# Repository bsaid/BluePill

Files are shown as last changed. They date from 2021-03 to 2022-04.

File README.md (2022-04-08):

# BluePill

This project is a mess and it has never been tested.

The goal is to make STM32F103C BluePill compatible PCB with safety resistors, robust power supply with protections and SD card addon using a stacked PCB. The project is designed in [KiCad](https://www.kicad.org/) with design rules for [JLCPCB](https://jlcpcb.com/) including SMT assembly with their LCSC parts library.

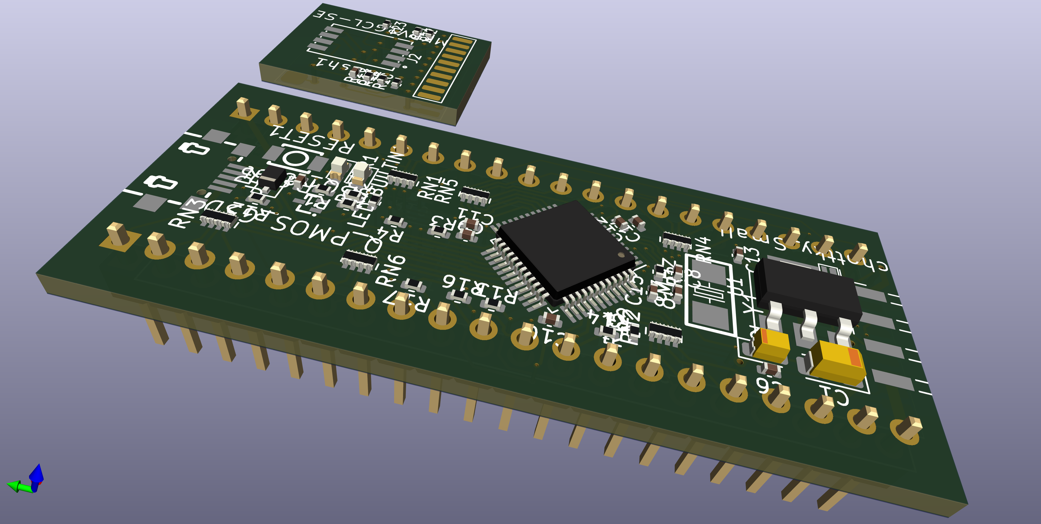
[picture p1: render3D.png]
Render


This PCB was never tested or manufactured because the STM32 microcontrollers are out of stock globally.

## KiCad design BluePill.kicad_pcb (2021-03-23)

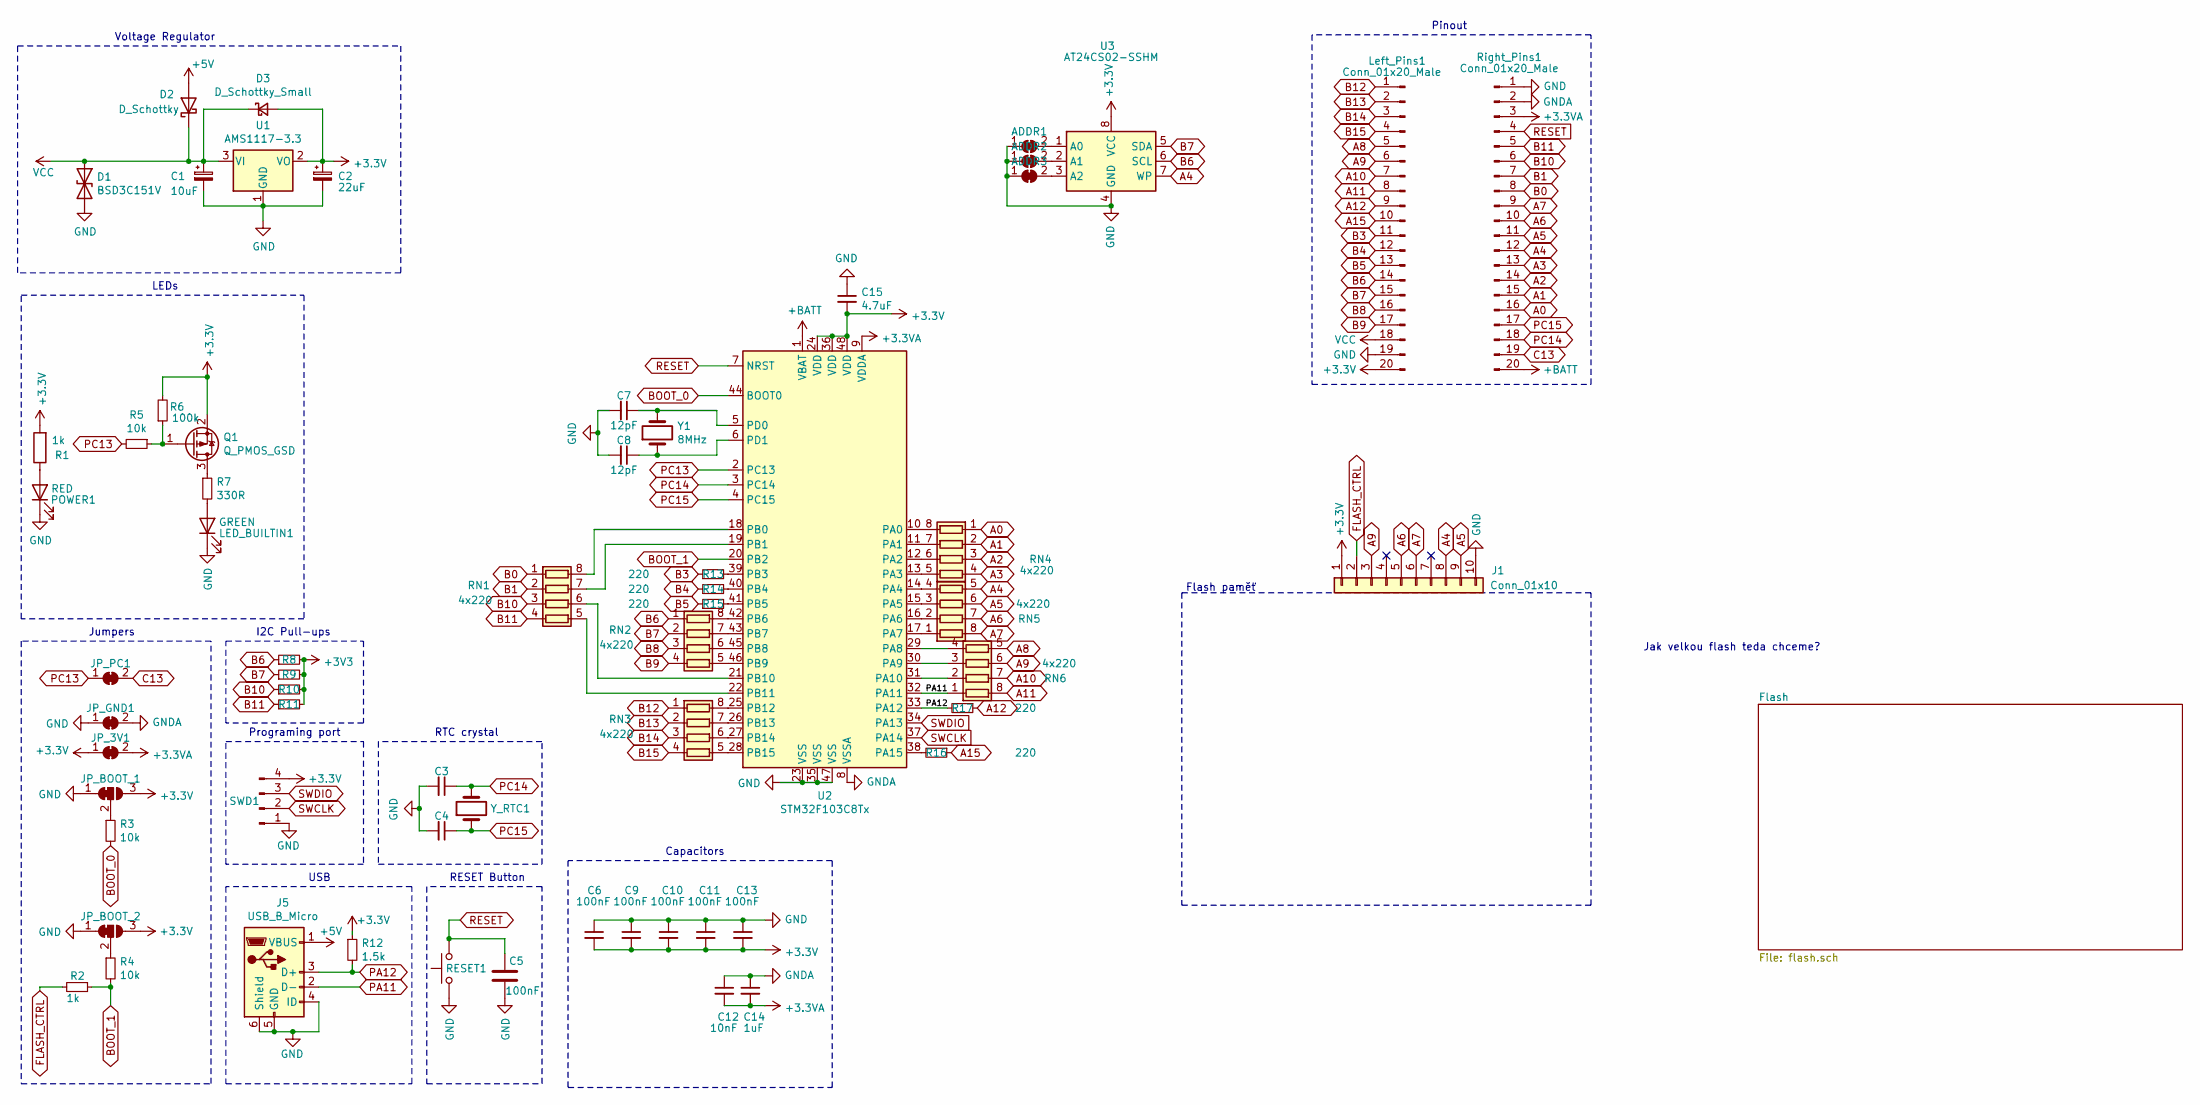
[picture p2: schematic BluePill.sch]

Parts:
ADDR1, ADDR2, ADDR3: GND; SolderJumper-2_P1.3mm_Bridged_RoundedPad1.0x1.5mm
C1: 10uF; CP_EIA-3216-18_Kemet-A; LCSC C117023
C2: 22uF; CP_EIA-2012-15_AVX-P; LCSC C11383
C3, C4: ?; C_0603_1608Metric_Pad1.08x0.95mm_HandSolder
C5, C6, C9, C10, C11, C13: 100nF; C_0402_1005Metric; LCSC C1525
C7, C8: 12pF; C_0402_1005Metric; LCSC C1547
C12: 10nF; C_0402_1005Metric; LCSC C15195
C14: 1uF; C_0402_1005Metric; LCSC C52923
C15: 4.7uF; C_0402_1005Metric; LCSC C23733
D1: BSD3C151V; R_1206_3216Metric_Pad1.30x1.75mm_HandSolder; LCSC C151990
D2: D_Schottky; D_SOD-323F; LCSC C78734
D3: D_Schottky_Small; DFN-2L_L1.0-W0.6-P0.65-RD; LCSC C134410
J1: Conn_01x10; Flash_connector
J5: USB_B_Micro; MICRO-USB-SMD_MICRO-USB-A11
JP_3V1: 3V3; SolderJumper-2_P1.3mm_Bridged_RoundedPad1.0x1.5mm
JP_BOOT_1: Boot 0; SolderJumper-3_P1.3mm_Bridged12_RoundedPad1.0x1.5mm
JP_BOOT_2: Boot 1; SolderJumper-3_P1.3mm_Bridged12_RoundedPad1.0x1.5mm
JP_GND1: GND; SolderJumper-2_P1.3mm_Bridged_RoundedPad1.0x1.5mm
JP_PC1: C13; SolderJumper-2_P1.3mm_Bridged_RoundedPad1.0x1.5mm
LED_BUILTIN1: GREEN; LED_0603_1608Metric; LCSC C72043
Left_Pins1: Conn_01x20_Male; PinHeader_1x20_P2.54mm_Vertical
POWER1: RED; LED_0603_1608Metric_Castellated; LCSC C2286
Q1: Q_PMOS_GSD; VBTA2245M; LCSC C692958
R1, R2: 1k; R_0402_1005Metric; LCSC C11702
R3, R4, R5: 10k; R_0402_1005Metric; LCSC C25744
R6: 100k; R_0402_1005Metric; LCSC C25741
R7: 330R; R_0402_1005Metric; LCSC C25104
R8, R9, R10, R11: ?; R_0603_1608Metric_Pad0.98x0.95mm_HandSolder
R12: 1.5k; R_0402_1005Metric; LCSC C25867
R13, R14, R15, R16, R17: 220; R_0402_1005Metric; LCSC C25091
RESET1: Reset; KEY-SMD_B3U-1000PM; LCSC C231329
RN1, RN2, RN3, RN4, RN5, RN6: 4x220; R_Array_Concave_4x0402; LCSC C25498
Right_Pins1: Conn_01x20_Male; PinHeader_1x20_P2.54mm_Vertical
SWD1: SWD; Harwin_M20-89004xx_1x04_P2.54mm_Horizontal
U1: AMS1117-3.3; SOT-223-3_TabPin2; LCSC C6186
U2: STM32F103C8Tx; LQFP-48_7x7mm_P0.5mm; LCSC C8734
U3: AT24CS02-SSHM; SOIC-8_3.9x4.9mm_P1.27mm
Y1: 8MHz; OSC-SMD_L5.0-W3.2; LCSC C156253
Y_RTC1: ?; Crystal_SMD_5032-2Pin_5.0x3.2mm_HandSoldering

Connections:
+3.3VA: C12.2, C14.2, JP_3V1.2 (B), Right_Pins1.3, U2.9 (VDDA)
+5V: D2.2 (A), J5.1 (VBUS)
+BATT: Right_Pins1.20, U2.1 (VBAT)
A0: RN4.1 (R1.1), Right_Pins1.16
A1: RN4.2 (R2.1), Right_Pins1.15
A2: RN4.3 (R3.1), Right_Pins1.14
A3: RN4.4 (R4.1), Right_Pins1.13
A4: J1.8, RN5.5 (R4.2), Right_Pins1.12, U3.7 (WP)
A5: J1.9, RN5.6 (R3.2), Right_Pins1.11
A6: J1.5, RN5.7 (R2.2), Right_Pins1.10
A7: J1.6, RN5.8 (R1.2), Right_Pins1.9
A8: Left_Pins1.5, RN6.5 (R4.2)
A9: J1.3, Left_Pins1.6, RN6.6 (R3.2)
A10: Left_Pins1.7, RN6.7 (R2.2)
A11: Left_Pins1.8, RN6.8 (R1.2)
A12: Left_Pins1.9, R17.1
A15: Left_Pins1.10, R16.1
B0: RN1.1 (R1.1), Right_Pins1.8
B1: RN1.2 (R2.1), Right_Pins1.7
B3: Left_Pins1.11, R13.1
B4: Left_Pins1.12, R14.1
B5: Left_Pins1.13, R15.1
B6: Left_Pins1.14, R8.1, RN2.1 (R1.1), U3.6 (SCL)
B7: Left_Pins1.15, R9.1, RN2.2 (R2.1), U3.5 (SDA)
B8: Left_Pins1.16, RN2.3 (R3.1)
B9: Left_Pins1.17, RN2.4 (R4.1)
B10: R10.1, RN1.3 (R3.1), Right_Pins1.6
B11: R11.1, RN1.4 (R4.1), Right_Pins1.5
B12: Left_Pins1.1, RN3.1 (R1.1)
B13: Left_Pins1.2, RN3.2 (R2.1)
B14: Left_Pins1.3, RN3.3 (R3.1)
B15: Left_Pins1.4, RN3.4 (R4.1)
BOOT_0: R3.2, U2.44 (BOOT0)
BOOT_1: R2.1, R4.2, U2.20 (PB2)
C13: JP_PC1.2 (B), Right_Pins1.19
FLASH_CTRL: J1.2, R2.2
GND: ADDR1.1 (A), ADDR2.1 (A), ADDR3.1 (A), C1.2, C2.2, C3.2, C4.2, C5.1, C6.1, C7.2, C8.2, C9.1, C10.1, C11.1, C13.1, C15.1, D1.2 (A2), J1.10, J5.4 (ID), J5.5 (GND), J5.6 (Shield), JP_BOOT_1.1 (A), JP_BOOT_2.1 (A), JP_GND1.1 (A), LED_BUILTIN1.1 (K), Left_Pins1.19, POWER1.1 (K), RESET1.1, Right_Pins1.1, SWD1.1, U1.1 (GND), U2.23 (VSS), U2.35 (VSS), U2.47 (VSS), U3.4 (GND)
GNDA: C12.1, C14.1, JP_GND1.2 (B), Right_Pins1.2, U2.8 (VSSA)
unnamed: ADDR1.2 (B), U3.1 (A0)
unnamed: ADDR2.2 (B), U3.2 (A1)
unnamed: ADDR3.2 (B), U3.3 (A2)
unnamed: C7.1, U2.5 (PD0), Y1.2
unnamed: C8.1, U2.6 (PD1), Y1.1
unnamed: JP_BOOT_1.2 (C), R3.1
unnamed: JP_BOOT_2.2 (C), R4.1
unnamed: LED_BUILTIN1.2 (A), R7.2
unnamed: POWER1.2 (A), R1.1
unnamed: Q1.1 (G), R5.1, R6.1
unnamed: Q1.3 (D), R7.1
unnamed: R13.2, U2.39 (PB3)
unnamed: R14.2, U2.40 (PB4)
unnamed: R15.2, U2.41 (PB5)
unnamed: R16.2, U2.38 (PA15)
unnamed: RN1.5 (R4.2), U2.22 (PB11)
unnamed: RN1.6 (R3.2), U2.21 (PB10)
unnamed: RN1.7 (R2.2), U2.19 (PB1)
unnamed: RN1.8 (R1.2), U2.18 (PB0)
unnamed: RN2.5 (R4.2), U2.46 (PB9)
unnamed: RN2.6 (R3.2), U2.45 (PB8)
unnamed: RN2.7 (R2.2), U2.43 (PB7)
unnamed: RN2.8 (R1.2), U2.42 (PB6)
unnamed: RN3.5 (R4.2), U2.28 (PB15)
unnamed: RN3.6 (R3.2), U2.27 (PB14)
unnamed: RN3.7 (R2.2), U2.26 (PB13)
unnamed: RN3.8 (R1.2), U2.25 (PB12)
unnamed: RN4.5 (R4.2), U2.13 (PA3)
unnamed: RN4.6 (R3.2), U2.12 (PA2)
unnamed: RN4.7 (R2.2), U2.11 (PA1)
unnamed: RN4.8 (R1.2), U2.10 (PA0)
unnamed: RN5.1 (R1.1), U2.17 (PA7)
unnamed: RN5.2 (R2.1), U2.16 (PA6)
unnamed: RN5.3 (R3.1), U2.15 (PA5)
unnamed: RN5.4 (R4.1), U2.14 (PA4)
unnamed: RN6.2 (R2.1), U2.31 (PA10)
unnamed: RN6.3 (R3.1), U2.30 (PA9)
unnamed: RN6.4 (R4.1), U2.29 (PA8)
PA11: J5.2 (D-), RN6.1 (R1.1), U2.32 (PA11)
PA12: J5.3 (D+), R12.2, R17.2, U2.33 (PA12)
PC13: JP_PC1.1 (A), R5.2, U2.2 (PC13)
PC14: C3.1, Right_Pins1.18, U2.3 (PC14), Y_RTC1.2
PC15: C4.1, Right_Pins1.17, U2.4 (PC15), Y_RTC1.1
RESET: C5.2, RESET1.2, Right_Pins1.4, U2.7 (NRST)
SWCLK: SWD1.2, U2.37 (PA14)
SWDIO: SWD1.3, U2.34 (PA13)
VCC: C1.1, D1.1 (A1), D2.1 (K), D3.1 (K), Left_Pins1.18, U1.3 (VI)

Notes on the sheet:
Jumpers
I2C Pull-ups
Programing port
USB
LEDs
RESET Button
Pinout
Voltage Regulator
Flash paměť
Capacitors
RTC crystal
Jak velkou flash teda chceme?

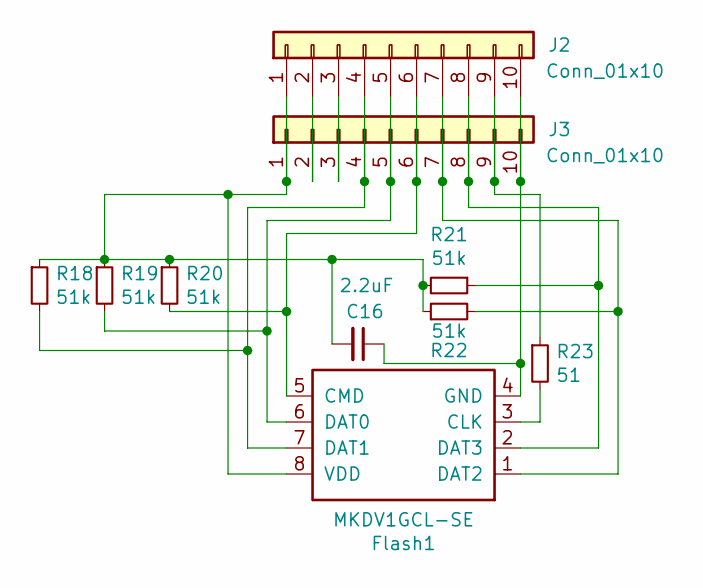
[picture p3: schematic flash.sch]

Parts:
C16: 2.2uF; C_0402_1005Metric; LCSC C12530
Flash1: MKDV1GCL-SE; LGA-8_L6.0-W8.0-P1.27-TL
J2: Conn_01x10; Flash_connector_2
J3: Conn_01x10; Flash_connector
R18, R19, R20, R21, R22: 51k; R_0402_1005Metric; LCSC C25794
R23: 51; R_0402_1005Metric; LCSC C25125

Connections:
unnamed: C16.1, Flash1.4 (GND), J2.10, J3.10
unnamed: C16.2, Flash1.8 (VDD), J2.1, J3.1, R18.1, R19.1, R20.1, R21.2, R22.1
unnamed: Flash1.1 (DAT2), J2.7, J3.7, R22.2
unnamed: Flash1.2 (DAT3), J2.8, J3.8, R21.1
unnamed: Flash1.3 (CLK), R23.2
unnamed: Flash1.5 (CMD), J2.6, J3.6, R20.2
unnamed: Flash1.6 (DAT0), J2.5, J3.5, R19.2
unnamed: Flash1.7 (DAT1), J2.4, J3.4, R18.2
unnamed: J2.2, J3.2
unnamed: J2.3, J3.3
unnamed: J2.9, J3.9, R23.1

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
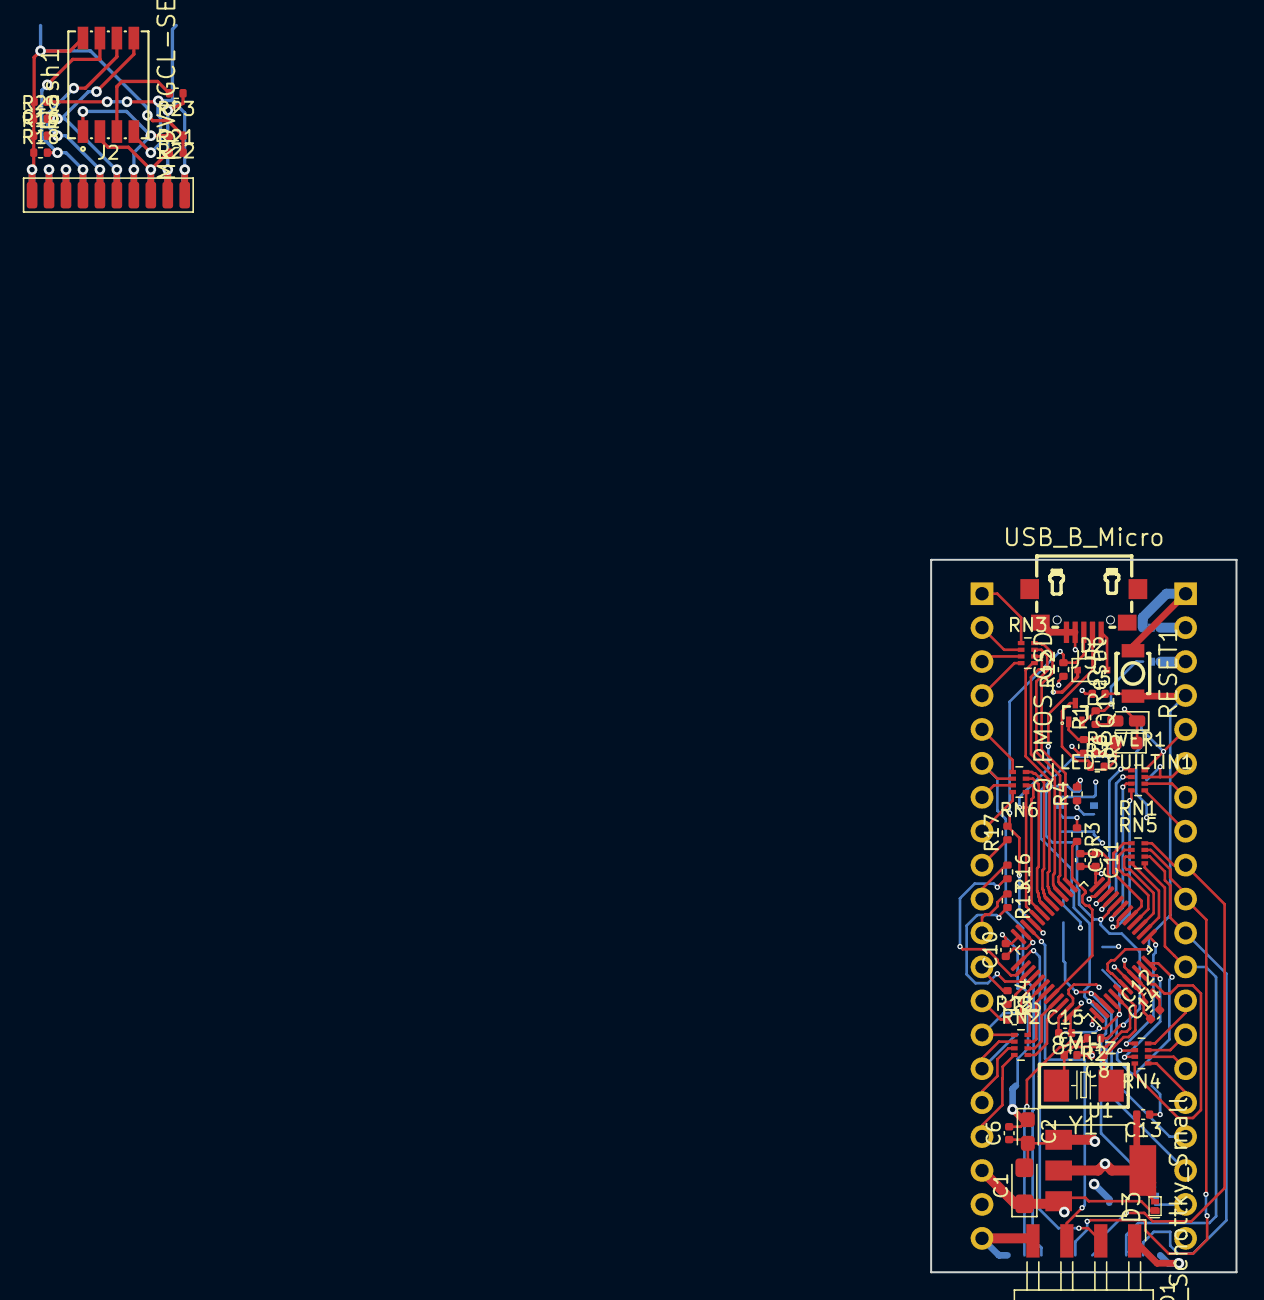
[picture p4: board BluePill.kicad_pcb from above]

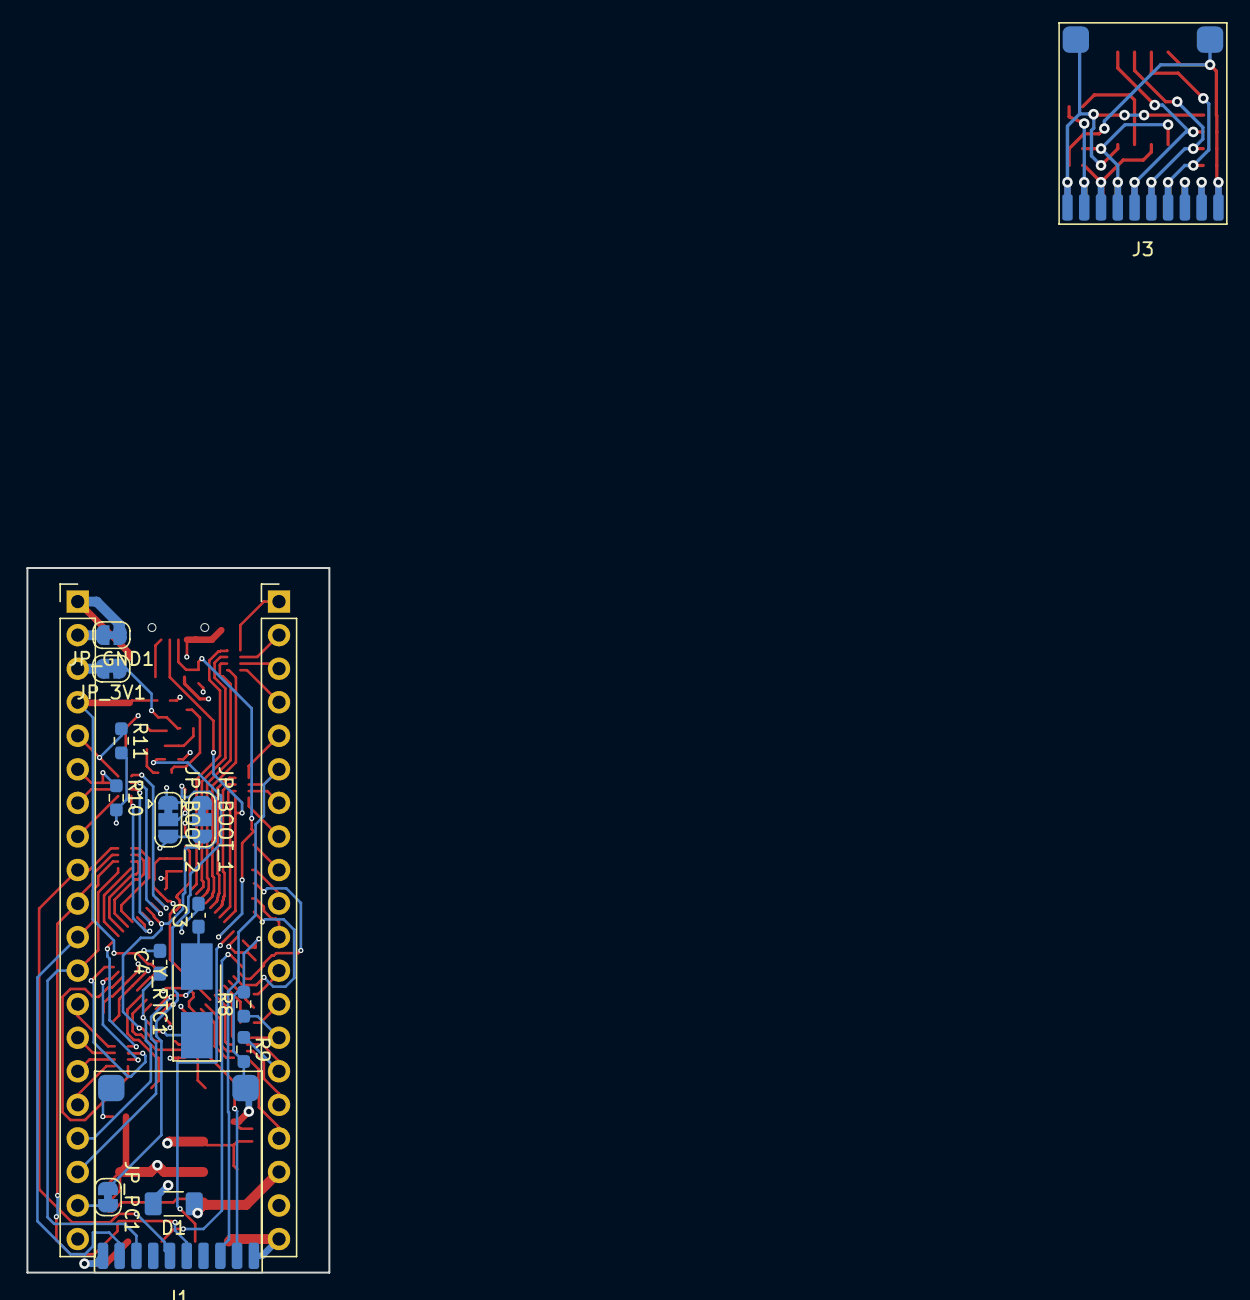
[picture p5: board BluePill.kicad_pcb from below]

Board: 4 copper layers, 22.9 x 53.3 mm, 69 parts (17 on the bottom side), 94 nets.

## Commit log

2020-09-12 Initial commit.
    [BluePill.brd, BluePill.csv, BluePill.sch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]
2020-09-16 Fix some warnings
    [BluePill.brd, BluePill.sch]
2020-09-19 Add paneled version
    [BOM.xlsx, BluePill-Panel.brd]
2020-09-19 Finish panelized version
    [BluePill-Panel.brd, BluePill.csv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]
2020-09-19 Generate new gerber files
    [BOM.xlsx, PnP_BluePill-Panel_back.csv, PnP_BluePill-Panel_front.csv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]
2021-03-02 Switch to KiCad
    [BOM.xlsx, BluePill-Panel.brd, BluePill.brd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]
2021-03-21 Finish schematic
    [BluePill.sch]
2021-03-21 Add LCSC numbers
    [BluePill.sch]
2021-03-23 Route board
    [BluePill.kicad_pcb, BluePill.sch, flash.sch]
2022-04-08 Added 3D render of the PCB.
